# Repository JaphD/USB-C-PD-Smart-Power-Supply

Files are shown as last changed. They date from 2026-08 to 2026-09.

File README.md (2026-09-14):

# PD Smart Supply

A USB-C Power Delivery supply designed by Yafet Daniel. Rev A uses an STM32 controller to select a PD voltage, control a protected output, and measure output voltage and current. An OLED and three pushbuttons provide the user interface.

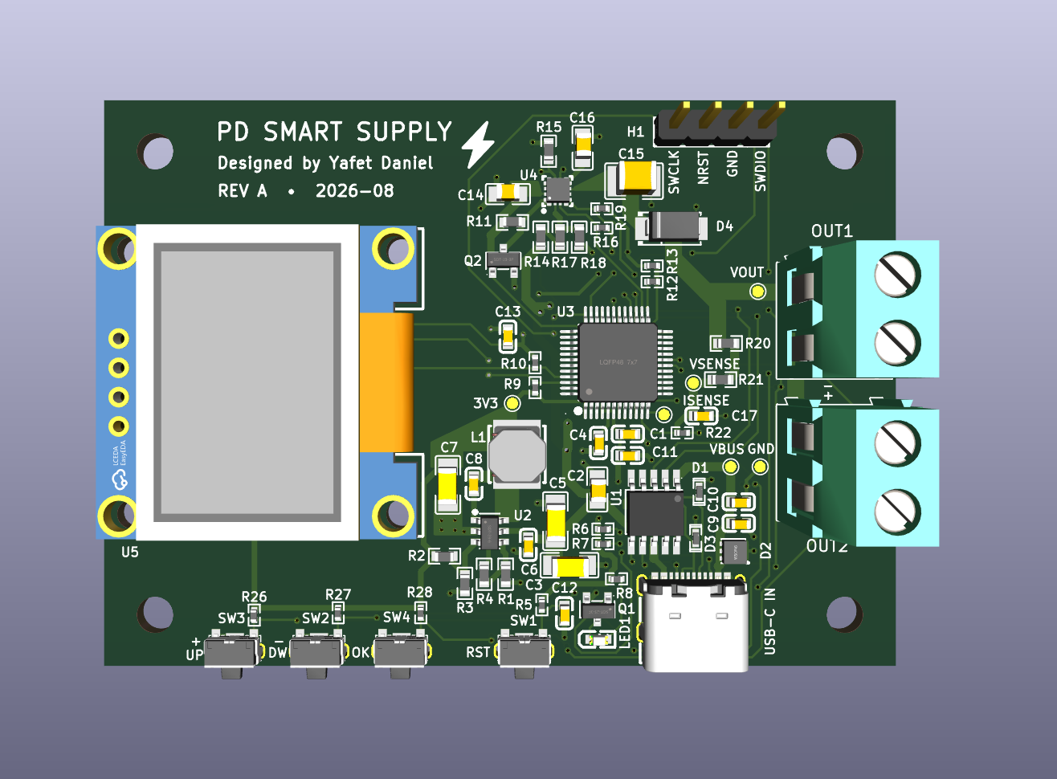
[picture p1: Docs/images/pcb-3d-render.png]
Rev A PCB 3D render


## Specifications

| Parameter | Design specification |
|---|---|
| Input | USB-C Power Delivery through a CH224A controller |
| Output voltage selections | 5 V, 9 V, 12 V, and 20 V |
| Rated output | Up to 3 A total, 60 W at 20 V |
| Output connectors | Two parallel screw terminals sharing one protected output |
| Controller | STM32G071CBT6 |
| Output protection | TPS259470L eFuse with MCU shutdown and fault monitoring |
| Hardware current limit | Approximately 3.76 A nominal; rated output remains 3 A |
| Monitoring | Output voltage and current sensing through the MCU ADC |
| User interface | I²C OLED, Up/Down/Select buttons, and PD status LED |
| Internal power rail | 3.3 V from a TPS560430 buck converter |
| Debug interface | SWD |
| PCB | 70 × 50 mm, four layers, nominal 1.6 mm thickness |

Available output voltages and power depend on the connected PD source and cable. Voltage selection uses discrete PD requests; the design does not provide continuously variable voltage or programmable constant-current regulation. The two outputs share the 3 A rating. The design excludes 15 V and 28 V operation.

## Hardware

The USB-C input feeds the protected output through the eFuse. A separate buck converter powers the controller and interface from the negotiated input voltage. The hardware includes VBUS transient protection, output overvoltage cutoff, controlled startup, and voltage/current test points.

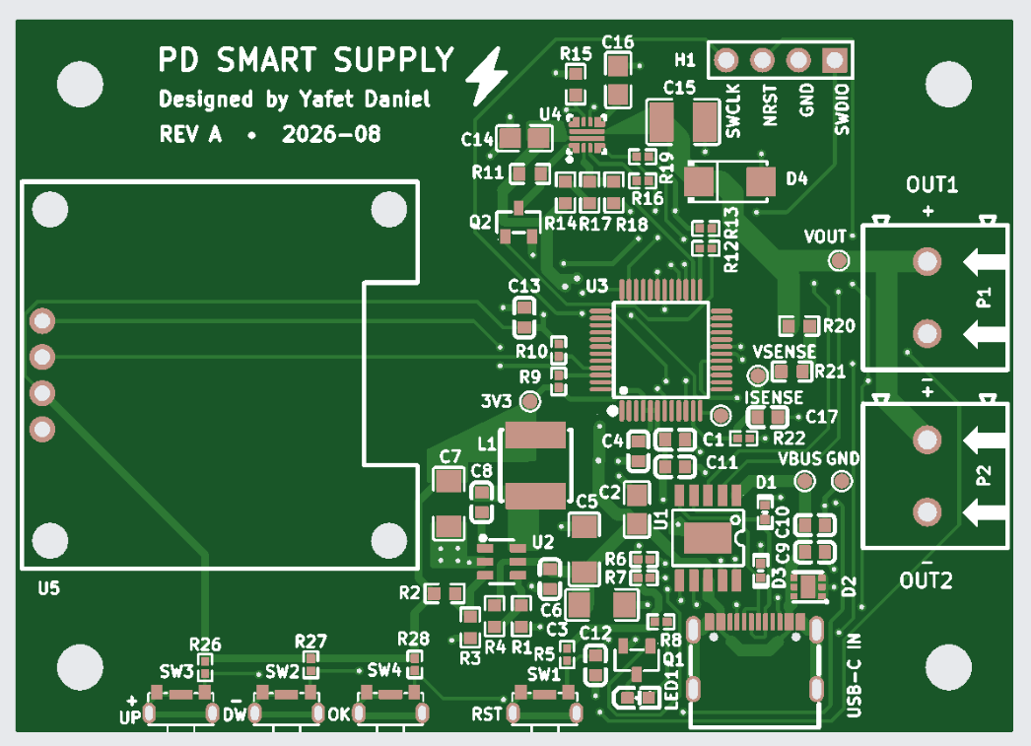
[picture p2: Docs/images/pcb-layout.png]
Rev A PCB layout


## Project status

The Rev A schematic and four-layer PCB layout are complete and prepared for manufacturing. The repository includes a generated STM32CubeIDE project configured for a 64 MHz system clock, ADC voltage and current sensing, I²C, control and status GPIO, and SWD debugging. PD selection logic, display operation, button handling, and application fault handling remain to be implemented. The ratings above are design targets, not measured performance results.

## Repository contents

- `PD Smart Supply.kicad_pro`, `.kicad_sch`, and `.kicad_pcb`: KiCad project, schematic, and board layout.
- `PD Smart Supply.kicad_dru`: project-specific PCB design rules.
- `Firmware/`: STM32CubeMX configuration, STM32CubeIDE project files, generated firmware sources, and device libraries.
- `Docs/PD_Smart_Supply_Rev_A_Design_Record.pdf`: design record.
- `Docs/Sim/`: LTspice eFuse enable/shutdown simulation.
- `Docs/images/`: PCB layout and 3D render images.

Open `PD Smart Supply.kicad_pro` in KiCad 9 to inspect the hardware. Custom libraries and manufacturer references under `Lib/` and `Docs/Ref/` are excluded from Git, so library paths may need to be restored for editing. Open `Firmware/Firmware.ioc` in STM32CubeMX or import `Firmware/` into STM32CubeIDE to inspect or regenerate the firmware project.

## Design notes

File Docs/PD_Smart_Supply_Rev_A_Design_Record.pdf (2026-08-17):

PD Smart Supply - Rev A | Page 1

# PD SMART SUPPLY

## REV A DESIGN DEFINITION AND BUILD RECORD

Designer | Yafet Daniel | Revision | A
Date | August 2026 | Status | Design complete

## 1. PURPOSE AND SCOPE

PD Smart Supply is a compact USB-C Power Delivery powered programmable supply. It requests a selected PD voltage, protects and monitors the power path, and provides two parallel protected outputs. An STM32 microcontroller manages voltage selection, supervision, display and user input. Rev A is intended as a functional engineering prototype.

## 2. PRINCIPAL SPECIFICATIONS

Item | Specification
Input | USB-C PD through a USB4105-GF-A receptacle
Selectable output | 5 V, 9 V, 12 V and 20 V; 28 V intentionally disabled
Maximum output | 20 V at 3 A, approximately 60 W
Output connectors | Two parallel outputs sharing a combined 3 A rating
Controller | STM32G071CBT6
Display | HS96L03W2C03, 0.96 inch, 128 x 64, I2C OLED
Controls | UP, DOWN, SELECT and RESET tactile buttons
Board | 70 x 50 mm, four layers, nominal 1.6 mm FR-4

## 3. SYSTEM ARCHITECTURE

Main power path: USB-C input -> CH224A PD controller -> VBUS_PD -> TPS259470L eFuse -> EFUSE_OUT -> OUT1 and OUT2.

Auxiliary power path: VBUS_PD -> TPS560430 buck converter -> 3.3 V logic rail -> MCU, OLED and control circuitry.

The two output connectors are electrically parallel. Their total permitted load is 3 A, not 3 A per connector.

### USB-C PD control

The CH224A negotiates the requested source voltage. CC1 and CC2 connect directly to the controller. USB D+ and D- are routed as a short pair for charging-protocol support. Three MCU control lines select the requested voltage. Firmware must not generate the CH224A state that requests 28 V because the Rev A protection design is limited to 20 V.

## 4. POWER PROTECTION AND REGULATION

### Protected output

The TPS259470L eFuse provides inrush control, current limiting, monitoring and MCU-controlled shutdown. A TVS2200 protects VBUS_PD, and the output clamp diode limits negative transients.

Parameter | Rev A value
User output rating | 3 A combined across OUT1 and OUT2
Nominal current limit | Approximately 3.76 A using 887 ohm RILM
Overvoltage threshold | Approximately 22.1 V
Output slew rate | Approximately 0.91 V/ms; about 22 ms to 20 V
Fail-safe state | eFuse defaults off while the MCU is in reset

### 3.3 V supply

A TPS560430 buck converter derives the 3.3 V rail from VBUS_PD. The stage uses a 10 uH inductor, 22 uF output capacitor and 51 k / 22.1 k feedback divider. The switching loop and feedback network are kept compact and separated from analog sensing.

## 5. MEASUREMENT AND CONTROL

Signal | Purpose or scaling | MCU
VOUT_SENSE | VOUT / 10.98; approximately 1.82 V at 20 V | PA0 ADC
IOUT_SENSE | Approximately 0.161 V/A; 0.484 V at 3 A | PA1 ADC
EFUSE_nFLT | Active-low fault indication | PB15
EFUSE_READY | Valid input and completed inrush indication | PB14
EFUSE_OFF | High disables the protected output | PB13

### User and service interfaces

Interface | Implementation
Navigation | UP, DOWN and SELECT buttons with 10 k pull-ups
Reset | Dedicated pushbutton connected to NRST
Display | 128 x 64 I2C OLED operating from 3.3 V
Status LED | Driven from CH224A power-good logic through a 2N7002
Debug | Four-pin SWD header: SWDIO, SWCLK, NRST and GND
Test points | VBUS_PD, 3V3, VOUT, VOUT_SENSE, IOUT_SENSE and GND

## 6. FIRMWARE REQUIREMENTS

Firmware shall permit only 5 V, 9 V, 12 V and 20 V selections; keep the eFuse disabled until startup checks pass; wait approximately 5 ms after voltage changes before accepting VOUT_SENSE; and use EFUSE_nFLT for fault response. EFUSE_READY alone is not a complete fault indicator.

## 7. PCB IMPLEMENTATION

Item | Rev A definition
Fabricator target | JLCPCB stackup JLC04161H-7628
Dimensions | 70 x 50 mm
Layer order | F.Cu signal/power - In1.Cu ground - In2.Cu power - B.Cu signal/ground
Finished thickness | KiCad model 1.6062 mm; nominal order thickness 1.6 mm
Copper | 1 oz outer layers; 0.5 oz inner layers
Finish | HAL SnPb, green solder mask, white silkscreen
Assembly population | 63 references in the verified BOM and placement file

### Layout

The high-current path runs directly from USB-C through protection and the eFuse to the output connectors. In1 is the continuous ground reference. The buck switching node is compact, analog sense traces are kept away from the inductor, and ground stitching is concentrated around the USB, protection, buck, MCU and connector regions.

## 8. MANUFACTURING STATUS

Check | Result
Routing | Complete; final verification found zero unconnected items
Fabrication package | Four copper layers, masks, paste, silkscreen, profile, PTH and NPTH drills verified
Assembly files | BOM and CPL match at 63 references; all BOM rows contain LCSC numbers
Accepted exception | USB clearance of 0.2462 mm against the project rule of 0.2500 mm
Nonfunctional warnings | Known footprint silkscreen clipping and mechanical/test-point parity warnings

### Procurement note

CH224A, JLCPCB/LCSC C42459160, was out of stock during the August 2026 quotation and was excluded from assembly. The exact ESSOP-10 device must be sourced and reflow-soldered before complete USB-PD operation can be tested.

## 9. INITIAL BRING-UP

Step | Required check
1 | Inspect assembly, component polarity and resistance to ground
2 | Apply current-limited 5 V and verify VBUS_PD and 3.3 V
3 | Program the MCU and verify reset, buttons, OLED and LED
4 | Fit and verify the CH224A if it was not assembled
5 | Test 5 V, 9 V, 12 V and 20 V negotiation without load
6 | Increase load gradually while checking regulation, sensing, protection and temperature

## 10. CONCLUSION

Rev A is design-complete and ready for prototype manufacture. Physical bring-up will validate electrical behavior, thermal performance, USB-PD interoperability, measurement accuracy, firmware control and enclosure integration before any Rev B changes are considered.

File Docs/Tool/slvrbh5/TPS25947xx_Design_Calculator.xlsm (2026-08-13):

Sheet: Calculation Sheet
TPS25947xx Design Calculation Tool
 |  |  |  |  |  |  |  |  | Table - 1: Device Comparison Table
 | Constants Cells |  |  |  |  |  |  |  | Part number | Overvoltage Response | Overcurrent response | AUXOFF or PG | FLT or PGTH | Response to Thermal Shutdown (TSD) |  | 3.8 | 5.7 | 13.8
 | Input/SelectCells |  |  |  |  |  |  |  | TPS259470A | Adjustable OVLO | Active Current Limit | AUXOFF | FLT | Auto-Retry |  | Short | Open | 390
 | Calculation Cells |  |  |  |  |  |  |  | TPS259470L | Adjustable OVLO | Active Current Limit | AUXOFF | FLT | Latch-off
 | Calculated, but can be over-ridden by user |  |  |  |  |  |  |  | TPS259472A | Pin Selectable OVC (3.8 V/5.7 V/13.8 V) | Active Current Limit | PG | PGTH | Auto-Retry
 | Error Cells, Must be Fixed |  |  |  |  |  |  |  | TPS259472L | Pin Selectable OVC(3.8 V/5.7 V/13.8 V) | Active Current Limit | PG | PGTH | Latch-off
 |  |  |  |  |  |  |  |  | TPS259474A | Adjustable OVLO | Circuit Breaker | PG | PGTH | Auto-retry
Parameter | Description | Value | Units | Tolerance | Recommended Value |  |  |  | TPS259474L | Adjustable OVLO | Circuit Breaker | PG | PGTH | Latch-off
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

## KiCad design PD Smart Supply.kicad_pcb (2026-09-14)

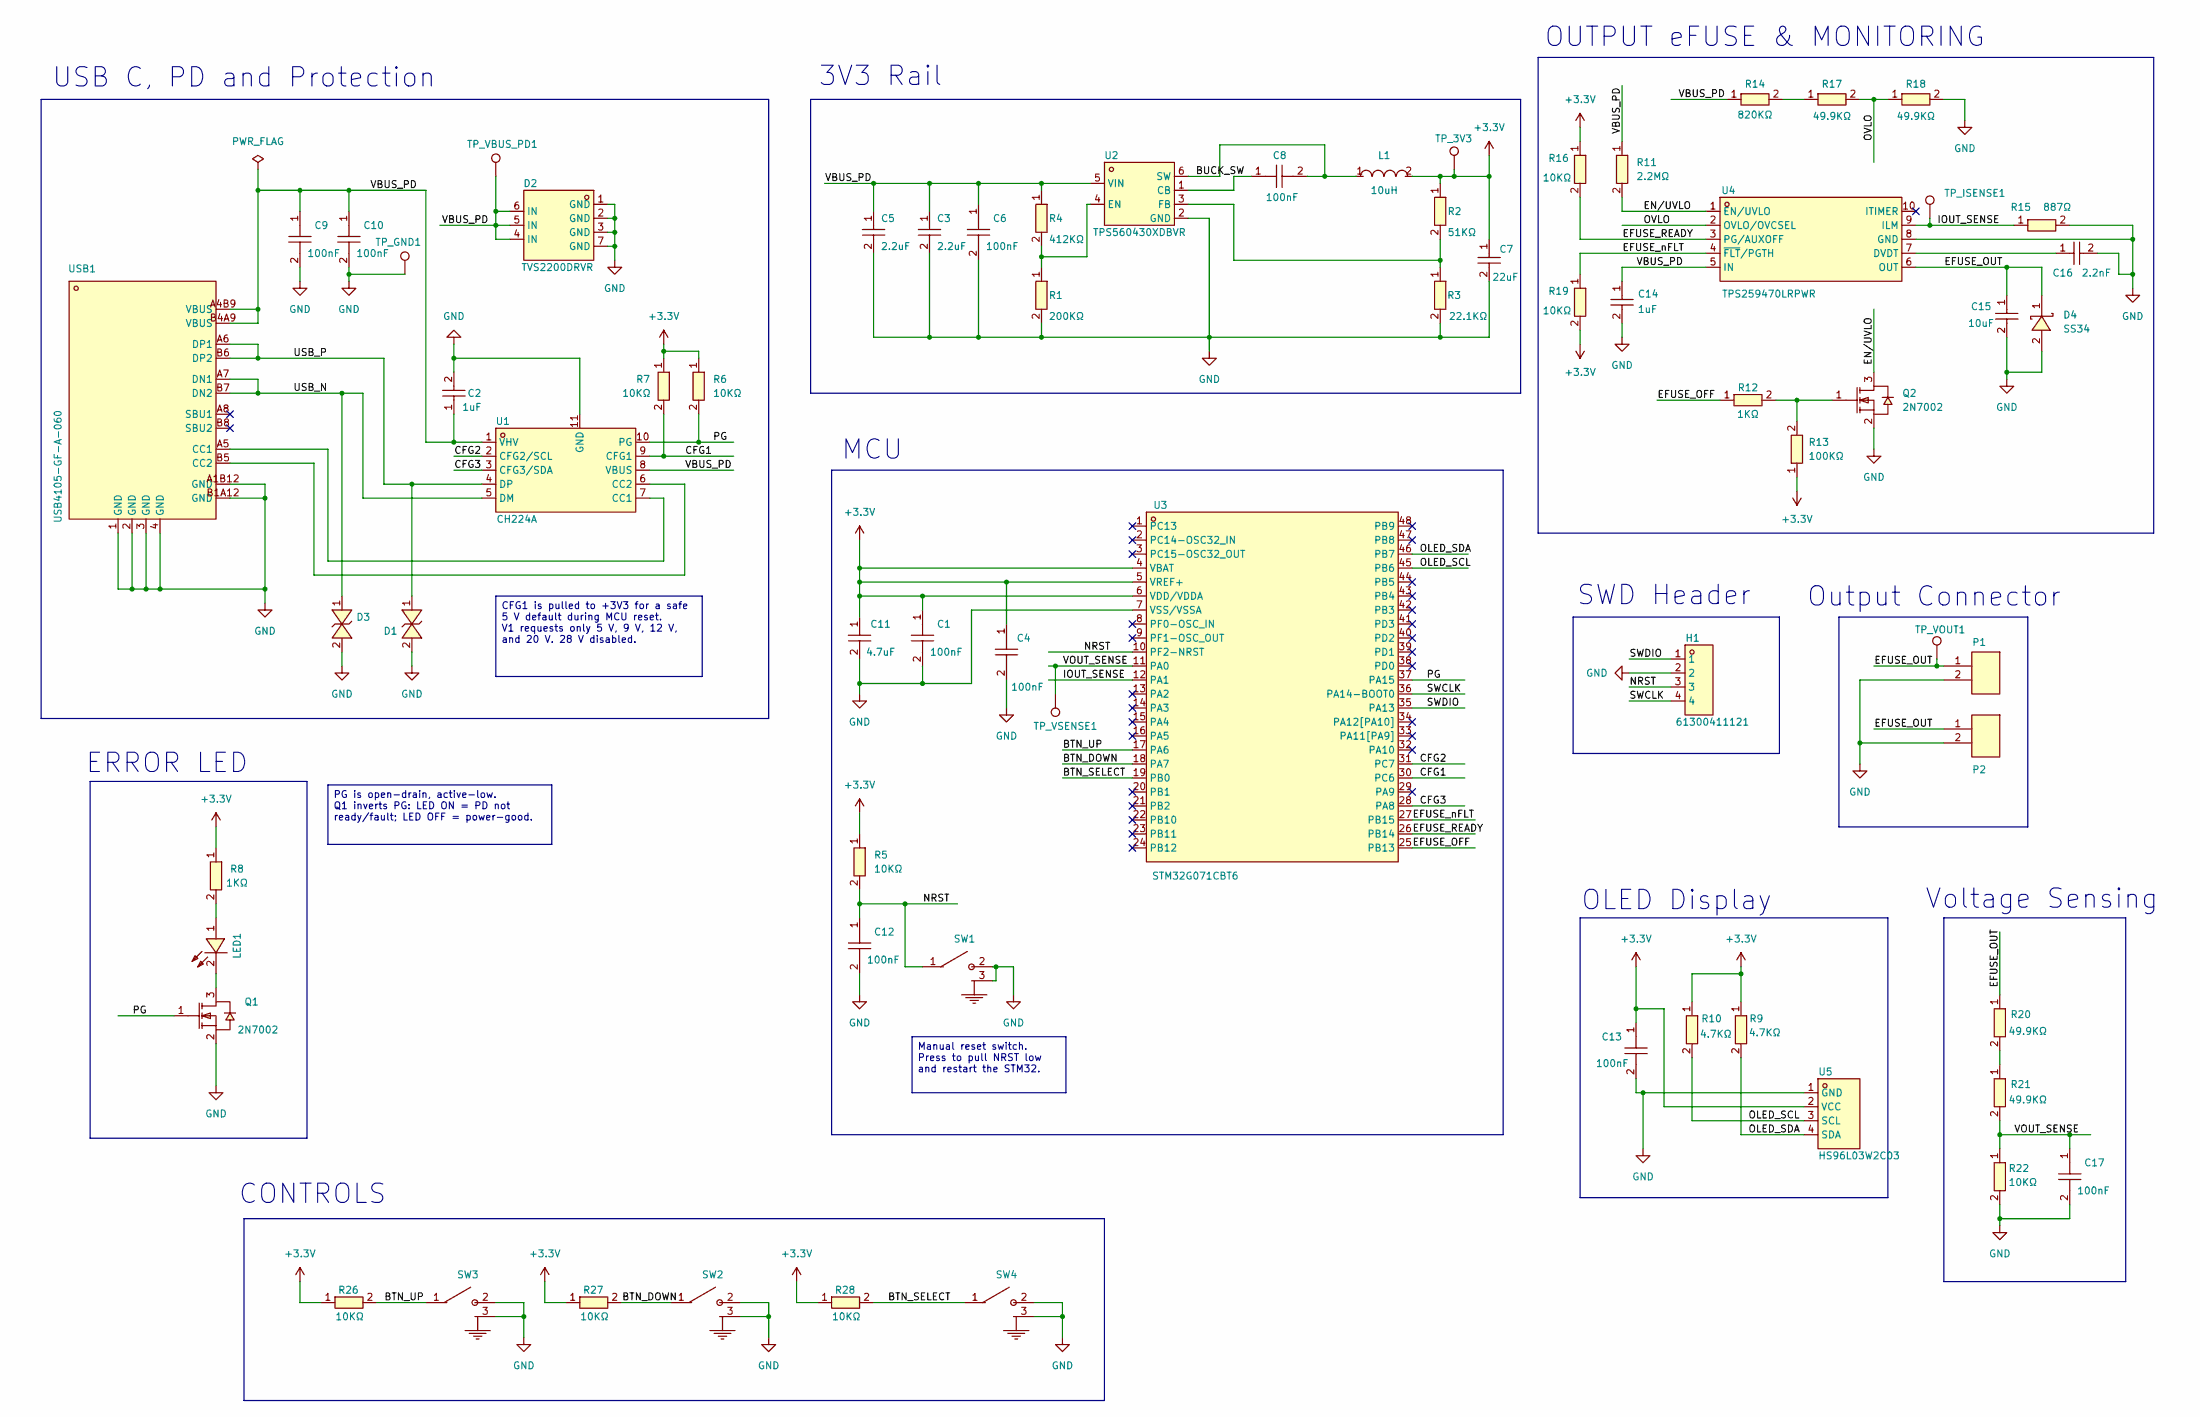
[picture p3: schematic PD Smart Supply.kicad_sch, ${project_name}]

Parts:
C1, C4, C6, C8, C9, C10, C12, C13, C17: 100nF; C0603; MPN CC0603KRX7R9BB104; LCSC Part C14663
C2, C14: 1uF; C0805; MPN CL21B105KBFNNNE; LCSC Part C28323
C3, C5: 2.2uF; C1206; MPN CL31B225KBHNNNE; LCSC Part C50254
C7: 22uF; C1206; MPN 1206B226K100NT; LCSC Part C105475
C11: 4.7uF; C0603; MPN CL21A475KAQNNNE; LCSC Part C1779
C15: 10uF; C1210; MPN CL32B106KBJNFNE; LCSC Part C18739
C16: 2.2nF; C0805; MPN CL21C222JBFNNNE; LCSC Part C28260
D1, D3: GG0402052R542P; D0402-BI; MPN GG0402052R542P; LCSC Part C1973257
D2: TVS2200DRVR; WSON-6_L2.0-W2.0-P0.65-BL-EP; MPN TVS2200DRVR; LCSC Part C523793
D4: SS34; SMA_L4.3-W2.6-LS5.2-RD; MPN SS34; LCSC Part C8678
H1: 61300411121; HDR-TH_4P-P2.54-V-M-1; MPN 61300411121; LCSC Part C5184785
L1: 10uH; IND-SMD_L5.0-W5.0_FNR50XXS; MPN FNR5040S100MT; LCSC Part C167967
LED1: KT-0603R; LED-SMD_L1.6-W0.8-R-RD; MPN KT-0603R; LCSC Part C2286
P1, P2: WJ500V-5.08-2P-14-00A; CONN-TH_2P-P5.00_WJ500V-5.08-2P; MPN WJ500V-5.08-2P; LCSC Part C8465
Q1, Q2: 2N7002; SOT-23-3_L2.9-W1.3-P1.90-LS2.4-BR; MPN 2N7002; LCSC Part C8545
R1: 200KΩ; R0603; MPN RS-03K2003FT; LCSC Part C95331
R2: 51KΩ; R0603; MPN 0603WAF5102T5E; LCSC Part C23196
R3: 22.1KΩ; R0603; MPN RC0603FR-0722K1L; LCSC Part C137768
R4: 412KΩ; R0603; MPN 0603WAF4123T5E; LCSC Part C23050
R5, R6, R7, R16, R19, R22, R26, R27, R28: 10KΩ; R0402; MPN 0402WGF1002TCE; LCSC Part C25744
R8, R12: 1KΩ; R0402; MPN 0402WGF1001TCE; LCSC Part C11702
R9, R10: 4.7KΩ; R0402; MPN 0402WGF4701TCE; LCSC Part C25900
R11: 2.2MΩ; R0603; MPN 0603WAF2204T5E; LCSC Part C22938
R13: 100KΩ; R0402; MPN 0402WGF1003TCE; LCSC Part C25741
R14: 820KΩ; R0603; MPN 0603WAF8203T5E; LCSC Part C23252
R15: 887Ω; R0603; MPN 0603WAF8870T5E; LCSC Part C93619
R17, R18, R20, R21: 49.9KΩ; R0603; MPN RC0603FR-0749K9L; LCSC Part C114624
SW1, SW2, SW3, SW4: TSC01-TBW0FH3.5; SW-SMD_XYECONN_TSC01-TBW0FH3.5; MPN TSC01-TBW0FH3.5; LCSC Part C22362977
TP_3V3: TestPoint; TestPoint_Pad_D1.0mm
TP_GND1: TestPoint; TestPoint_Pad_D1.0mm
TP_ISENSE1: TestPoint; TestPoint_Pad_D1.0mm
TP_VBUS_PD1: TestPoint; TestPoint_Pad_D1.0mm
TP_VOUT1: TestPoint; TestPoint_Pad_D1.0mm
TP_VSENSE1: TestPoint; TestPoint_Pad_D1.0mm
U1: CH224A; ESSOP-10_L4.9-W3.9-P1.0-LS6.0-TL-EP; MPN CH224A; LCSC Part C42459160
U2: TPS560430XDBVR; SOT-23-6_L2.9-W1.6-P0.95-LS2.8-BL; MPN TPS560430XDBVR; LCSC Part C524782
U3: STM32G071CBT6; LQFP-48_L7.0-W7.0-P0.50-LS9.0-BL; MPN STM32G071CBT6; LCSC Part C432212
U4: TPS259470LRPWR; VQFN-10_L2.0-W2.0-P0.45-TL; MPN TPS259470LRPWR; LCSC Part C3662793
U5: HS96L03W2C03; OLED-TH_L27.8-W27.2-P2.54_C9900033791; MPN HS96L03W2C03; LCSC Part C5248080
USB1: USB4105-GF-A-060; USB-C-SMD_GT-USB-7010E-1; MPN USB4105-GF-A-060; LCSC Part C3025063

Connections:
+3.3V: C1.1, C4.1, C7.1, C11.1, C13.1, L1.2, R2.1, R5.1, R6.1, R7.1, R8.1, R9.1, R10.1, R13.1, R16.1, R19.2, R26.1, R27.1, R28.1, TP_3V3.1, U3.4 (VBAT), U3.5 (VREF+), U3.6 (VDD/VDDA), U5.2 (VCC)
/BTN_DOWN: R27.2, SW2.1, U3.18 (PA7)
/BTN_SELECT: R28.2, SW4.1, U3.19 (PB0)
/BTN_UP: R26.2, SW3.1, U3.17 (PA6)
/BUCK_SW: C8.2, L1.1, U2.6 (SW)
/CFG1: R7.2, U1.9 (CFG1), U3.30 (PC6)
/CFG2: U1.2 (CFG2/SCL), U3.31 (PC7)
/CFG3: U1.3 (CFG3/SDA), U3.28 (PA8)
/EFUSE_OFF: R12.1, U3.25 (PB13)
/EFUSE_OUT: C15.1, D4.1, P1.1, P2.1, R20.1, TP_VOUT1.1, U4.6 (OUT)
/EFUSE_READY: R16.2, U3.26 (PB14), U4.3 (PG/AUXOFF)
/EFUSE_nFLT: R19.1, U3.27 (PB15), U4.4 (~FLT/PGTH)
/EN/UVLO: Q2.3, R11.2, U4.1 (EN/UVLO)
/IOUT_SENSE: R15.1, TP_ISENSE1.1, U3.12 (PA1), U4.9 (ILM)
/NRST: C12.1, H1.3, R5.2, SW1.1, U3.10 (PF2-NRST)
/OLED_SCL: R10.2, U3.45 (PB6), U5.3 (SCL)
/OLED_SDA: R9.2, U3.46 (PB7), U5.4 (SDA)
/OVLO: R17.2, R18.1, U4.2 (OVLO/OVCSEL)
/PG: Q1.1, R6.2, U1.10 (PG), U3.37 (PA15)
/SWCLK: H1.4, U3.36 (PA14-BOOT0)
/SWDIO: H1.1, U3.35 (PA13)
/USB_N: D3.1, U1.5 (DM), USB1.A7 (DN1), USB1.B7 (DN2)
/USB_P: D1.1, U1.4 (DP), USB1.A6 (DP1), USB1.B6 (DP2)
/VBUS_PD: C2.1, C3.1, C5.1, C6.1, C9.1, C10.1, C14.1, D2.4 (IN), D2.5 (IN), D2.6 (IN), R4.1, R11.1, R14.1, TP_VBUS_PD1.1, U1.1 (VHV), U1.8 (VBUS), U2.5 (VIN), U4.5 (IN), USB1.A4B9 (VBUS), USB1.B4A9 (VBUS)
/VOUT_SENSE: C17.1, R21.2, R22.1, TP_VSENSE1.1, U3.11 (PA0)
GND: C1.2, C2.2, C3.2, C4.2, C5.2, C6.2, C7.2, C9.2, C10.2, C11.2, C12.2, C13.2, C14.2, C15.2, C16.2, C17.2, D1.2, D2.1 (GND), D2.2 (GND), D2.3 (GND), D2.7 (GND), D3.2, D4.2, H1.2, P1.2, P2.2, Q1.2, Q2.2, R1.2, R3.2, R15.2, R18.2, R22.2, SW1.2, SW1.3, SW2.2, SW2.3, SW3.2, SW3.3, SW4.2, SW4.3, TP_GND1.1, U1.11 (GND), U2.2 (GND), U3.7 (VSS/VSSA), U4.8 (GND), U5.1 (GND), USB1.1 (GND), USB1.2 (GND), USB1.3 (GND), USB1.4 (GND), USB1.A1B12 (GND), USB1.B1A12 (GND)
unnamed: LED1.1, R8.2
unnamed: LED1.2, Q1.3
unnamed: Q2.1, R12.2, R13.2
unnamed: R14.2, R17.1
unnamed: R20.2, R21.1
unnamed: U1.7 (CC1), USB1.A5 (CC1)
unnamed: U1.6 (CC2), USB1.B5 (CC2)
unnamed: C8.1, U2.1 (CB)
unnamed: R1.1, R4.2, U2.4 (EN)
unnamed: R2.2, R3.1, U2.3 (FB)
unnamed: C16.1, U4.7 (DVDT)

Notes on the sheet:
MCU
USB C, PD and Protection
OLED Display
Output Connector
ERROR LED
OUTPUT eFUSE & MONITORING
CONTROLS
SWD Header
Voltage Sensing
3V3 Rail
CFG1 is pulled to +3V3 for a safe 5 V default during MCU reset. V1 requests only 5 V, 9 V, 12 V, and 20 V. 28 V disabled.
Manual reset switch. Press to pull NRST low and restart the STM32.
PG is open-drain, active-low. Q1 inverts PG: LED ON = PD not ready/fault; LED OFF = power-good.

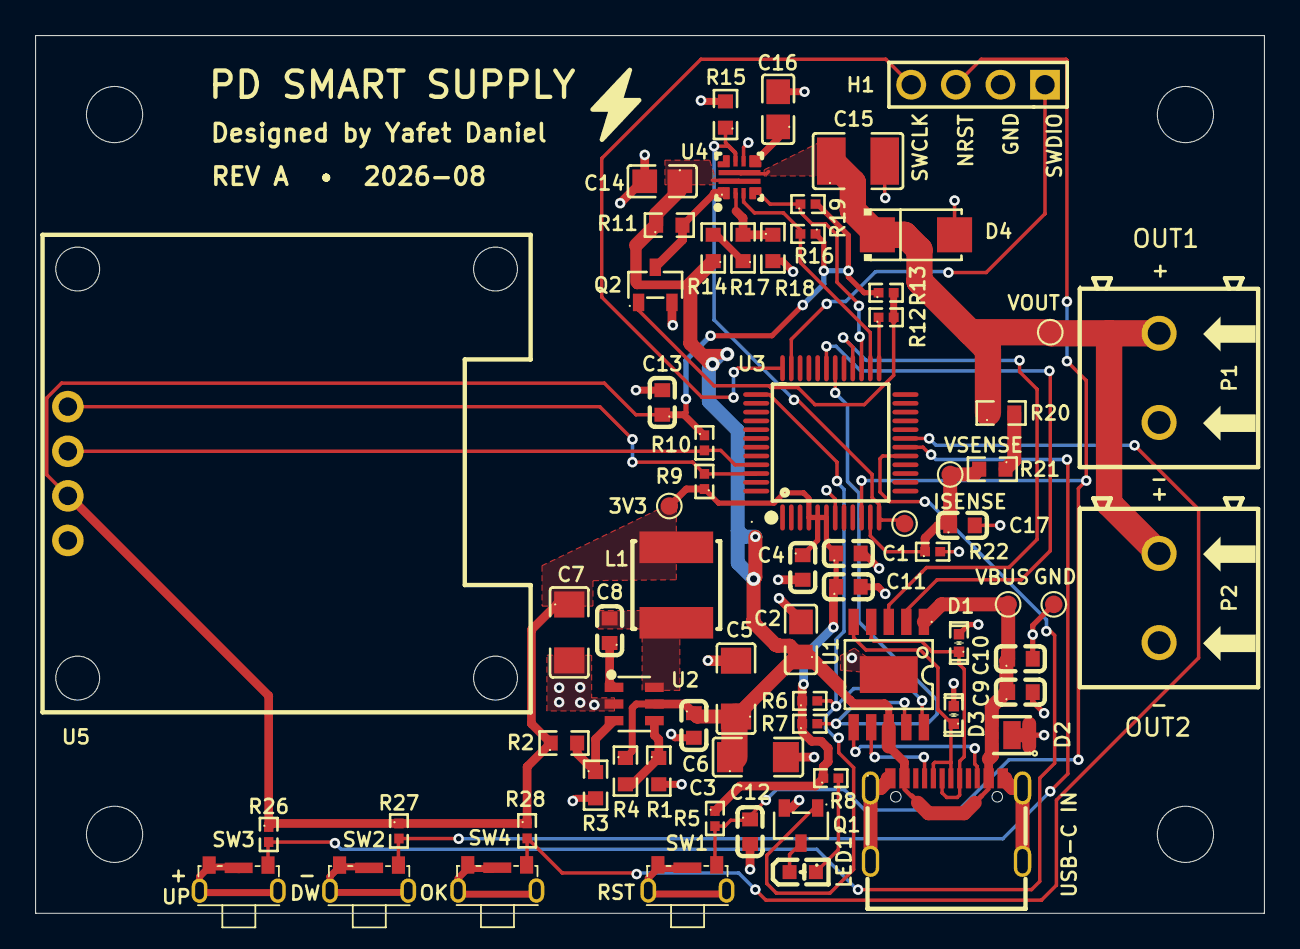
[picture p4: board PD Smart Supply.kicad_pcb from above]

Board: 4 copper layers, 70.0 x 50.0 mm, 69 parts (0 on the bottom side), 37 nets.

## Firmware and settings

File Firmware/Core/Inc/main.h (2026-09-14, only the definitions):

#define BTN_UP_Pin GPIO_PIN_6
#define BTN_UP_GPIO_Port GPIOA
#define BTN_DOWN_Pin GPIO_PIN_7
#define BTN_DOWN_GPIO_Port GPIOA
#define BTN_SELECT_Pin GPIO_PIN_0
#define BTN_SELECT_GPIO_Port GPIOB
#define EFUSE_OFF_Pin GPIO_PIN_13
#define EFUSE_OFF_GPIO_Port GPIOB
#define EFUSE_READY_Pin GPIO_PIN_14
#define EFUSE_READY_GPIO_Port GPIOB
#define EFUSE_nFLT_Pin GPIO_PIN_15
#define EFUSE_nFLT_GPIO_Port GPIOB
#define CFG3_Pin GPIO_PIN_8
#define CFG3_GPIO_Port GPIOA
#define CFG1_Pin GPIO_PIN_6
#define CFG1_GPIO_Port GPIOC
#define CFG2_Pin GPIO_PIN_7
#define CFG2_GPIO_Port GPIOC
#define PD_PG_Pin GPIO_PIN_15
#define PD_PG_GPIO_Port GPIOA

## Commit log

2026-07-09 Setup of eeschema for new project
    [PD Smart Supply.kicad_pcb, PD Smart Supply.kicad_sch]
2026-07-09 Remove KiCad lock file from tracking
2026-07-09 Added some major parts to the sheet
    [PD Smart Supply.kicad_sch]
2026-07-11 Finished schematic work for USB C, pd chip, board 3v3 regulator and added the mcu
    [PD Smart Supply.kicad_sch]
2026-08-08 feat: add MCU, SWD, OLED, error LED, and eFuse circuitry
    [PD Smart Supply.kicad_sch]
2026-08-13 Complete Rev A schematic with sensing and test points
    [PD Smart Supply.kicad_pcb, PD Smart Supply.kicad_sch, TPS25947xx_Design_Calculator.xlsm]
2026-08-17 Complete Rev A PCB layout and manufacturing preparation
    Finalize the four-layer placement, routing, ground pours, silkscreen branding, connector labels, and test-point markings.
    Add board design rules, fabrication toolkit settings, project documentation, and ignore regenerable plugin outputs.
    [PD Smart Supply.kicad_pcb, PD Smart Supply.kicad_sch]
2026-08-17 Finalize Rev A design for manufacturing
    Synchronize final component metadata and fabrication settings, preserve the completed PCB state, add the Rev A design record, and organize simulation and calculator references under Docs.
    [PD Smart Supply.kicad_pcb, PD Smart Supply.kicad_sch, TPS25947xx_Design_Calculator.xlsm]
2026-09-14 Add project README and PCB images
2026-09-14 Add CubeMX firmware setup and board dimensions
    [PD Smart Supply.kicad_pcb]
2026-09-14 Remove internal board setup specification
2026-09-14 Update README for current project state

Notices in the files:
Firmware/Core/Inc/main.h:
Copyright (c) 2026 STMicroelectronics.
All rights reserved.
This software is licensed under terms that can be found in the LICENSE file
